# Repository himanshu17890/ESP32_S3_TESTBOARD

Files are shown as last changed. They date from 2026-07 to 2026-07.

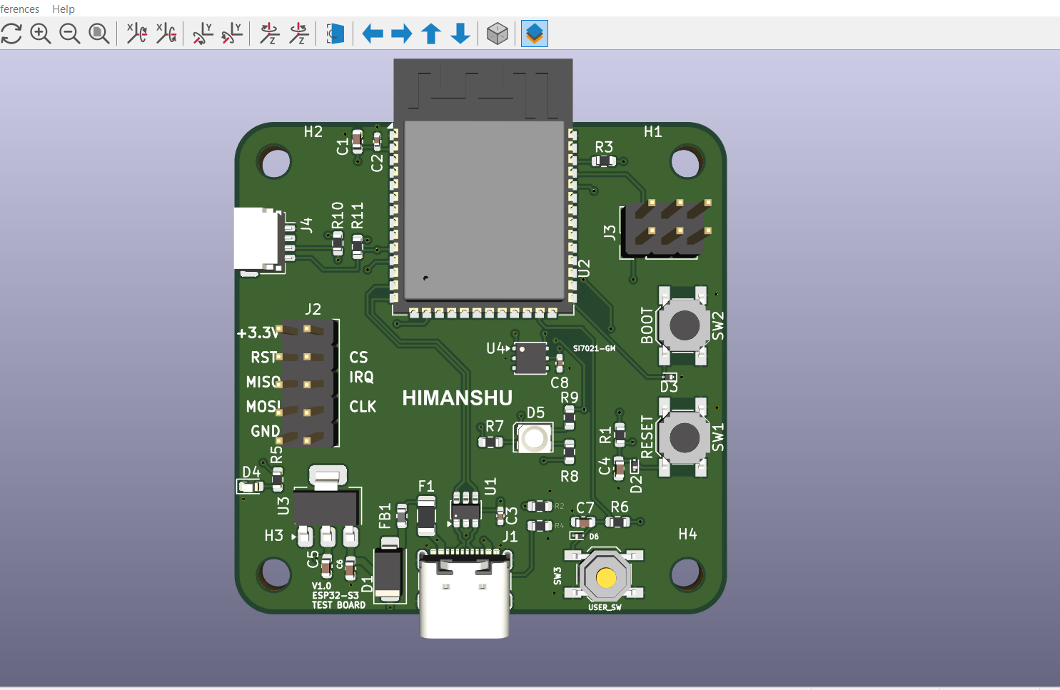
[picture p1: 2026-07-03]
Images/3D Top.png

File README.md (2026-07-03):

# ESP32-S3 IoT Development Board (KiCad PCB Design)

A custom **4-layer ESP32-S3 IoT development board** designed in **KiCad** for embedded and IoT applications.

> **Project Status:** PCB Design Completed (Not Fabricated)

---

# Project Overview

This project focuses on the complete schematic capture and PCB layout of an ESP32-S3 based development board intended for IoT and embedded system applications.

The board was designed following good PCB design practices, including component placement, routing, power distribution, USB differential pair routing, and design rule verification.

This repository contains the complete KiCad design files for learning, portfolio, and reference purposes.

---

# Features

- ESP32-S3-WROOM module
- 4-Layer PCB Design
- USB Type-C Interface
- USB ESD Protection
- 3.3V Power Regulation
- BOOT and RESET Buttons
- UART Programming Header
- QWIIC (I²C) Connector
- GPIO Expansion Header
- Power Status LED
- Design Rule Check (DRC) Verified
- Electrical Rule Check (ERC) Verified

---

# Tools Used

- KiCad 9
- PCB Editor
- Schematic Editor
- Interactive Router
- 3D Viewer

---

# Design Highlights

- Designed complete schematic from scratch
- Created 4-layer PCB layout
- Routed USB differential pair
- Implemented proper power distribution
- Added decoupling capacitors following ESP32 recommendations
- Implemented USB ESD protection
- Added programming and debugging interfaces
- Planned antenna keep-out region
- Performed ERC and DRC verification

---

# Hardware Specifications

| Feature | Details |
|---|---|
| MCU | ESP32-S3-WROOM |
| PCB Layers | 4 |
| USB | USB Type-C |
| Power | 3.3V |
| Programming | UART |
| Communication | UART, SPI, I²C |
| Expansion | QWIIC Connector |
| Design Software | KiCad 9 |

---

# Repository Structure

```
ESP32_S3_TESTBOARD
│
├── Hardware
│   ├── ESP32_S3_TESTBOARD.kicad_pro
│   ├── ESP32_S3_TESTBOARD.kicad_sch
│   └── ESP32_S3_TESTBOARD.kicad_pcb
│
├── Images
│   ├── PCB_Top.png
│   ├── PCB_Bottom.png
│   ├── 3D_Top.png
│   ├── 3D_Bottom.png
│   └── Schematic.png
│
├── Documents
│
├── README.md
├── LICENSE
└── .gitignore
```

---

# Images

## Schematic 
Schematic

---

## PCB Top

pcb_top

## 3D Top View

3D Top

---

## 3D Bottom View

3D BOTTOM

---

# PCB Design Workflow

1. Component Selection
2. Schematic Capture
3. Footprint Assignment
4. PCB Floor Planning
5. Component Placement
6. Interactive Routing
7. USB Differential Pair Routing
8. Power Plane Design
9. ERC Verification
10. DRC Verification
11. 3D Inspection

---

# Learning Outcomes

Through this project I gained practical experience in:

- Multi-layer PCB Design
- Schematic Capture
- ESP32 Hardware Design
- USB Interface Design
- PCB Component Placement
- Differential Pair Routing
- Power Distribution
- PCB Design Rules
- ERC and DRC Validation
- KiCad PCB Design Workflow

---

# Future Improvements

- PCB Fabrication
- Board Assembly
- Hardware Bring-up
- Firmware Development
- Functional Testing
- Power Consumption Analysis
- Sensor Expansion

---

# Note

This repository contains the **PCB design only**.

The hardware has **not been fabricated or tested**, and this project is intended to demonstrate PCB design skills using KiCad.

---

# Author

**Himanshu Pawar**

Electronics & Telecommunication Engineer

- LinkedIn: https://www.linkedin.com/in/himanshu-pawar-a74b732a9
- GitHub: https://github.com/himanshu17890

---

If you found this project useful, consider giving it a ⭐.

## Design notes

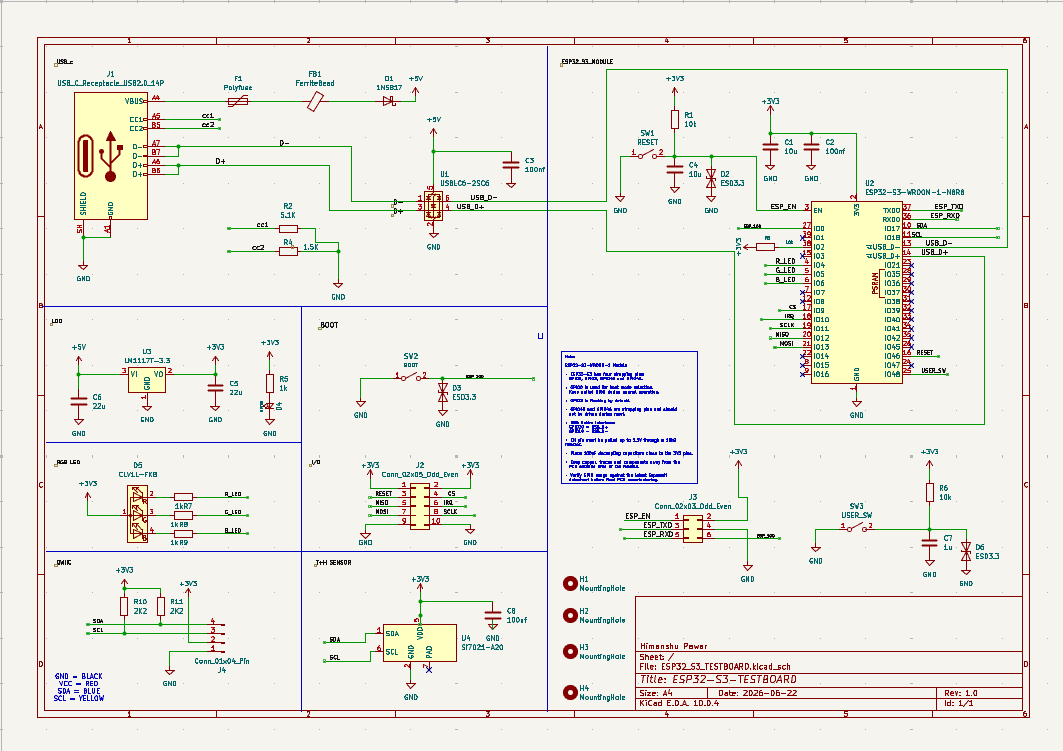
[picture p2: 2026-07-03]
Images/Schematic.png

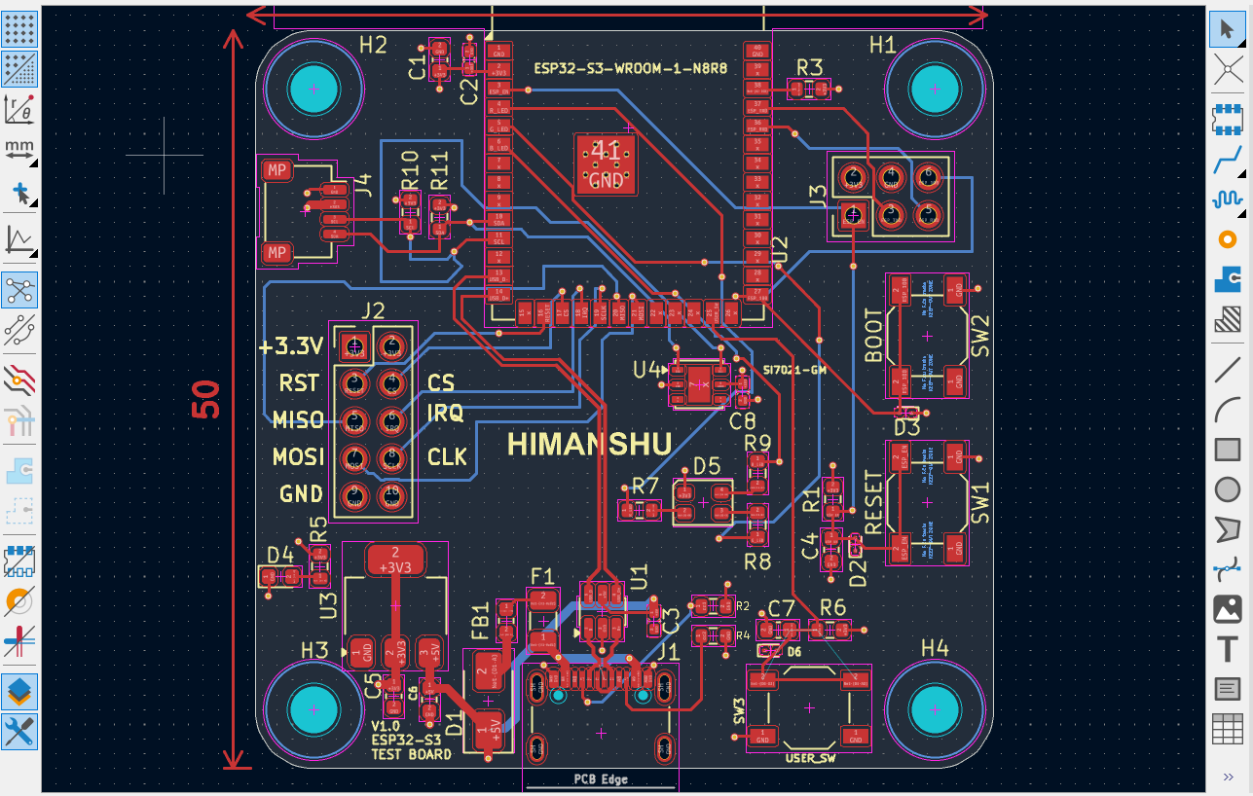
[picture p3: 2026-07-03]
Images/pcb_top.png

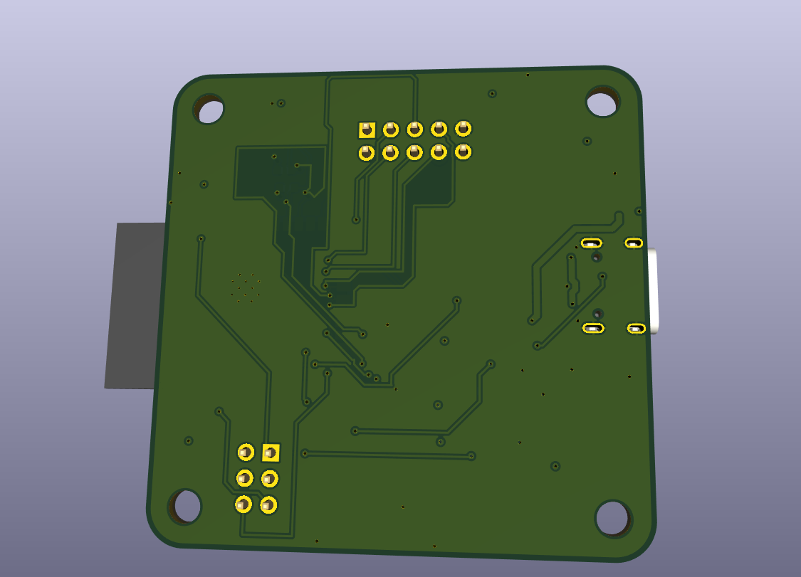
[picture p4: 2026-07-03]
Images/3D BOTTOM.png

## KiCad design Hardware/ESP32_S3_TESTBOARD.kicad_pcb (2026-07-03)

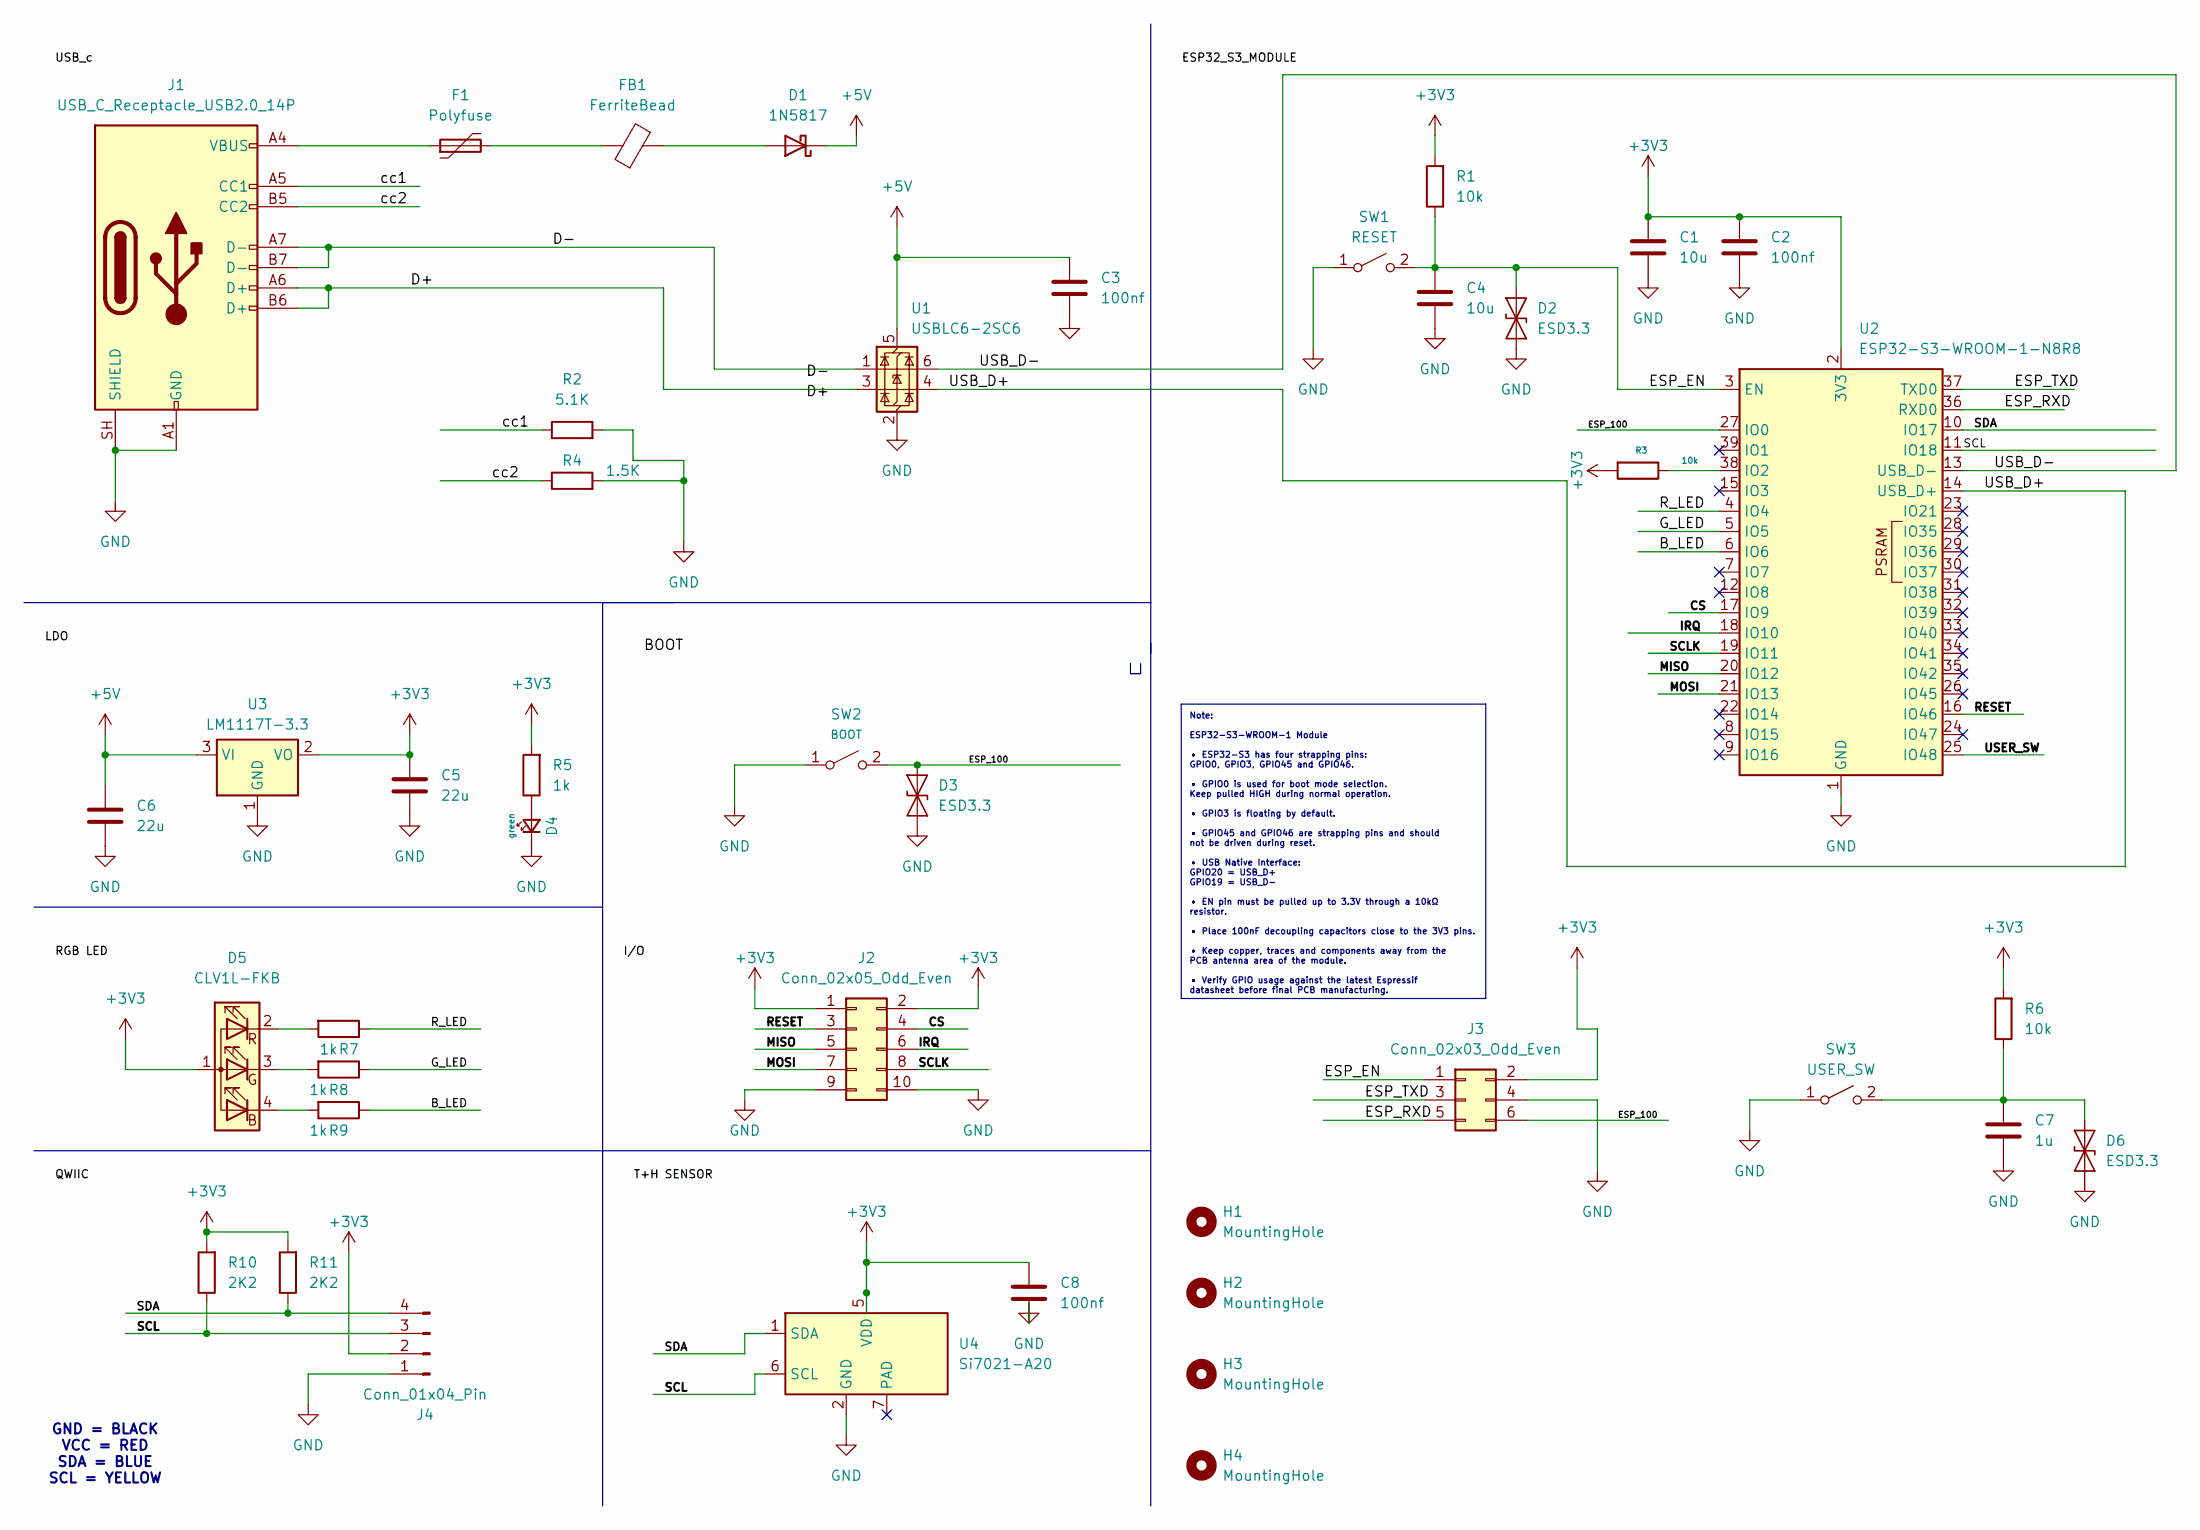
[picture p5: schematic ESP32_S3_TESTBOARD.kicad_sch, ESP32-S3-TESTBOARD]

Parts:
C1, C4: 10u; C_0603_1608Metric
C2, C8: 100nf; C_0402_1005Metric_Pad0.74x0.62mm_HandSolder
C3: 100nf
C5, C6: 22u; C_0603_1608Metric
C7: 1u; C_0603_1608Metric
D1: 1N5817; D_SMA
D2, D3, D6: ESD3.3; D_SOD-923
D4: green; LED_0603_1608Metric
D5: CLV1L-FKB; LED_Cree-PLCC4_3.2x2.8mm_CCW
F1: Polyfuse; Fuse_1206_3216Metric
FB1: FerriteBead; L_0603_1608Metric
H1, H2, H3, H4: MountingHole; MountingHole_3.2mm_M3
J1: USB_C_Receptacle_USB2.0_14P; USB_C_Receptacle_GCT_USB4105-xx-A_16P_TopMnt_Horizontal
J2: Conn_02x05_Odd_Even; PinHeader_2x05_P2.54mm_Vertical
J3: Conn_02x03_Odd_Even; PinHeader_2x03_P2.54mm_Vertical
J4: Conn_01x04_Pin; JST_SH_SM04B-SRSS-TB_1x04-1MP_P1.00mm_Horizontal
R1, R3, R6: 10k; R_0603_1608Metric
R2: 5.1K; R_0603_1608Metric
R4: 1.5K; R_0603_1608Metric
R5, R7, R8, R9: 1k; R_0603_1608Metric
R10, R11: 2K2; R_0603_1608Metric
SW1: RESET; SW_SPST_SKQG_WithoutStem
SW2: BOOT; SW_SPST_SKQG_WithoutStem
SW3: USER_SW; SW_SPST_TL3342
U1: USBLC6-2SC6; SOT-23-6
U2: ESP32-S3-WROOM-1-N8R8; ESP32-S3-WROOM-1
U3: LM1117T-3.3; SOT-223-3_TabPin2
U4: Si7021-A20; DFN-6-1EP_3x3mm_P1mm_EP1.5x2.4mm

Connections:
+3V3: C1.1, C2.1, C5.1, C8.1, D5.1 (A), J2.1, J2.2, J3.2, J4.2, R1.2, R3.2, R5.2, R6.2, R10.2, R11.2, U2.2 (3V3), U3.2 (VO), U4.5 (VDD)
+5V: C3.1, C6.1, D1.1 (K), U1.5 (VBUS), U3.3 (VI)
/B_LED: R9.1, U2.6 (IO6)
/CS: J2.4, U2.17 (IO9)
/D+: J1.A6 (D+), J1.B6 (D+), U1.3 (I/O2)
/D-: J1.A7 (D-), J1.B7 (D-), U1.1 (I/O1)
/ESP_100: D3.2 (A2), J3.6, SW2.2 (B), U2.27 (IO0)
/ESP_EN: C4.1, D2.2 (A2), J3.1, R1.1, SW1.2 (B), U2.3 (EN)
/ESP_RXD: J3.5, U2.36 (RXD0)
/ESP_TXD: J3.3, U2.37 (TXD0)
/G_LED: R8.1, U2.5 (IO5)
/IRQ: J2.6, U2.18 (IO10)
/MISO: J2.5, U2.20 (IO12)
/MOSI: J2.7, U2.21 (IO13)
/RESET: J2.3, U2.16 (IO46)
/R_LED: R7.1, U2.4 (IO4)
/SCL: J4.3, R10.1, U2.11 (IO18), U4.6 (SCL)
/SCLK: J2.8, U2.19 (IO11)
/SDA: J4.4, R11.1, U2.10 (IO17), U4.1 (SDA)
/USB_D+: U1.4 (I/O2), U2.14 (USB_D+)
/USB_D-: U1.6 (I/O1), U2.13 (USB_D-)
/USER_SW: U2.25 (IO48)
/cc1: J1.A5 (CC1), R2.1
/cc2: J1.B5 (CC2), R4.1
GND: C1.2, C2.2, C3.2, C4.2, C5.2, C6.2, C7.2, C8.2, D2.1 (A1), D3.1 (A1), D4.1 (K), D6.1 (A1), J1.A1 (GND), J1.A12 (GND), J1.B1 (GND), J1.B12 (GND), J1.SH (SHIELD), J2.9, J2.10, J3.4, J4.1, R2.2, R4.2, SW1.1 (A), SW2.1 (A), SW3.1 (A), U1.2 (GND), U2.1 (GND), U2.40 (GND), U2.41 (GND), U3.1 (GND), U4.2 (GND)
unnamed: D1.2 (A), FB1.2
unnamed: D4.2 (A), R5.1
unnamed: D5.4 (BK), R9.2
unnamed: D5.3 (GK), R8.2
unnamed: D5.2 (RK), R7.2
unnamed: C7.1, D6.2 (A2), R6.1, SW3.2 (B)
unnamed: F1.1, J1.A4 (VBUS), J1.A9 (VBUS), J1.B4 (VBUS), J1.B9 (VBUS)
unnamed: F1.2, FB1.1
unnamed: R3.1, U2.38 (IO2)

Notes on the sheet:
GND = BLACK VCC = RED SDA = BLUE SCL = YELLOW
Note: ESP32-S3-WROOM-1 Module • ESP32-S3 has four strapping pins: GPIO0, GPIO3, GPIO45 and GPIO46. • GPIO0 is used for boot mode selection. Keep pulled HIGH during normal operation. • GPIO3 is floating by default. • GPIO45 and GPIO46 are strapping pins and should not be driven during reset. • USB N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

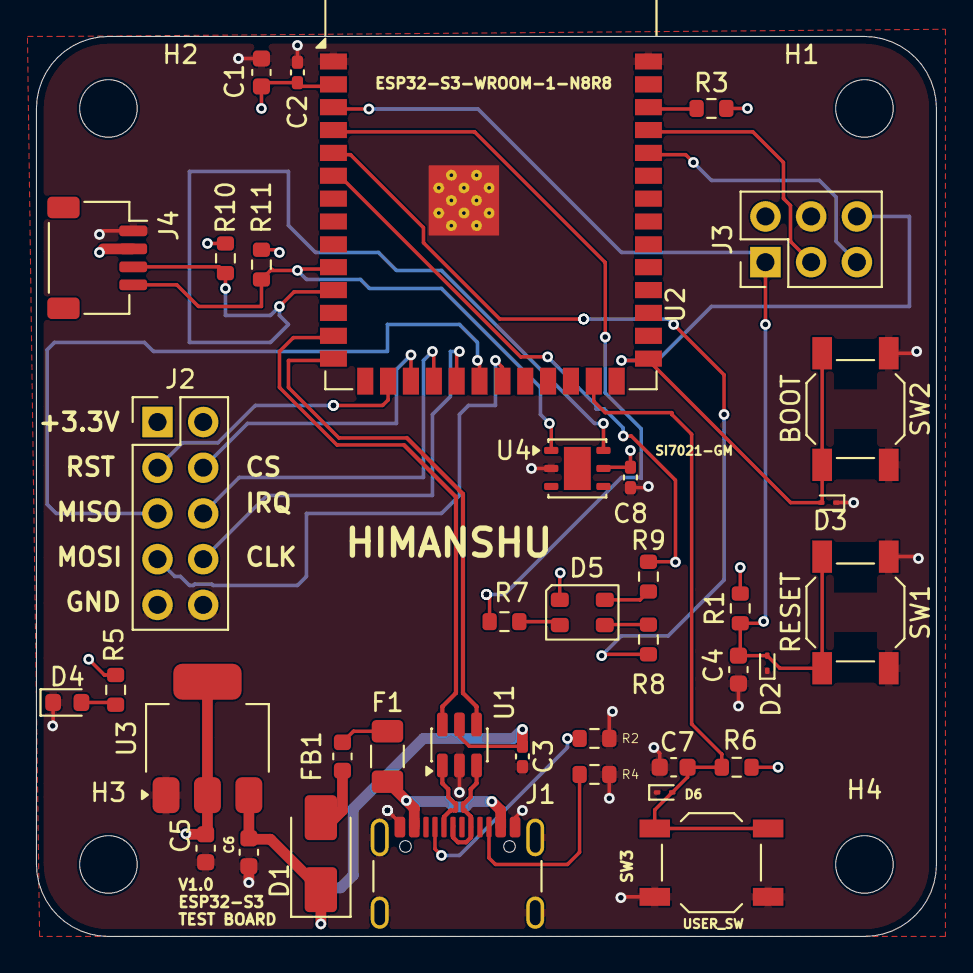
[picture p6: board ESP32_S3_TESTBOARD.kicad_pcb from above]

Board: 4 copper layers, 50.0 x 50.0 mm, 42 parts (0 on the bottom side), 33 nets.

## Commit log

2026-07-03 Add KiCad project files
    [ESP32_S3_TESTBOARD.kicad_pcb, ESP32_S3_TESTBOARD.kicad_sch]
2026-07-03 Organize repository structure
    [ESP32_S3_TESTBOARD.kicad_pcb, ESP32_S3_TESTBOARD.kicad_sch]
